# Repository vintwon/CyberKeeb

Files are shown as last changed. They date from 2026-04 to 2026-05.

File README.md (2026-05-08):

# CyberKeeb
render

## Some info...
This started as boredom, and evolved into my second keyboard! The theme came from some inspiration I saw from another keyboard on reddit, so I decided to do something similar. I wanted to use a rpi pico w but I didn't want to have extra space at the edge of the board, so I decided to make a daughterboard type situation. 
There are holes here: 



The traces are connected to the holes on the board which will then be connected to the rpi pico w which is mounted here using wires:



This way the usb-c port is centered in the back of the board and It gives me room to make the centerpiece of the keyboard:



Oh! And here is the pcb!





I went with a green and black theme simply because those are the colors of filament I have available right now. The geometrically interesting features are layerd, with each color on a different layer to provide depth. 
**ALSO QMK IS BEING USED YAYYY**

## BOM
!!! WARNING: ALIEXPRESS PRICES ARE VOLATILE AND SUBJECT TO CHAGE !!!

| Item | Link | Price(USD) | Notes |
|---|---|---|---|
| | | | |
| PCB | you must order the pcb yourself through your preferred pcb manufacturer. | ~$32 with shipping | Shipping and import taxes vary, for me it costs $32 on jlcpcb, which is the cheapest I could find. |
| KTT Kang White Switches | https://www.aliexpress.com/item/3256806762410255.html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 | $12.15 total | |
| DO-35 1N4148 diodes | https://www.aliexpress.com/item/3256811531564621.html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 | $2 | |
| Raspberry Pi Pico W | https://www.aliexpress.com/item/3256811531564621.html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 | $2 | |
| DUROCK stabilizers | https://www.aliexpress.com/item/3256806342416791.html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 | $3.85 | |
| Lubricant | https://www.aliexpress.com/item/3256803007713392.html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 | $9.67(for one) | Buy two |
| | | | |
| Total | | $71.34 | ALIEXPRESS PRICES ARE VOLATILE!!!! |

### <a href="https://cad.onshape.com/documents/5317cbb2be7b5bc0767f3a0c/">CAD in onshape :3</a>


## Zine!!!

zine-1

## Build instructions coming soon!

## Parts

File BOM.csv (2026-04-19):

Item | Link | Price(USD) | Notes
PCB | you must order the pcb yourself through your preferred pcb manufacturer. | ~$32 with shipping | Shipping and import taxes vary, for me it costs $32 on jlcpcb, which is the cheapest I could find.
Milky Yellow Pro Switches | https://www.aliexpress.com/item/3256803874880557.html?mp=1 | (2x needed) $13.82 total | make sure to order two!
DO-35 1N4148 diodes | https://www.aliexpress.com/item/3256811531564621.html?mp=1 | $1.85
Raspberry Pi Pico W | https://www.aliexpress.com/item/3256811531564621.html?mp=1 | $2
DUROCK stabilizers | https://www.aliexpress.com/item/3256806342416791.html?mp=1 | $3.85
Total |  | $53.52 | ALIEXPRESS PRICES ARE VOLATILE!!!!

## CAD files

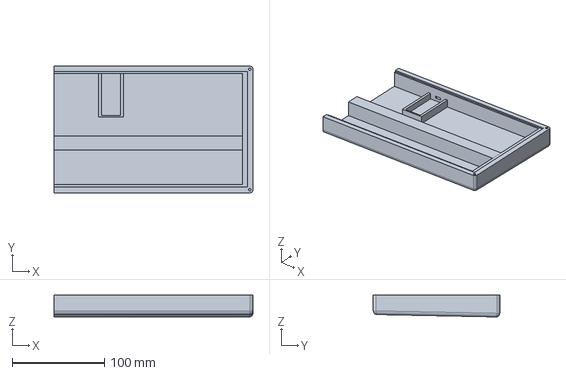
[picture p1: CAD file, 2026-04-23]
STEP files/Bottom Case/Case - Bottom Case.step
216.1 x 137.4 x 23.8 mm

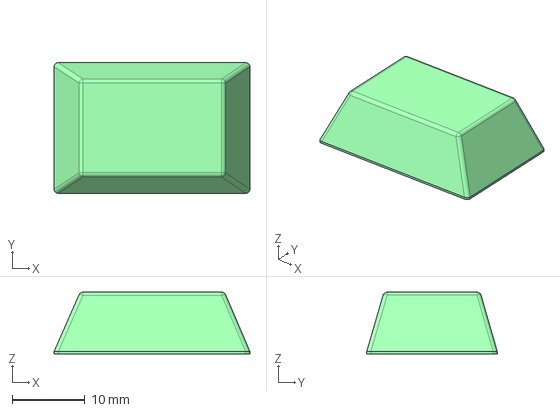
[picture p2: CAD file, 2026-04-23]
STEP files/keycaps/Keycaps - 1.5u.step
27.0 x 18.0 x 8.50 mm

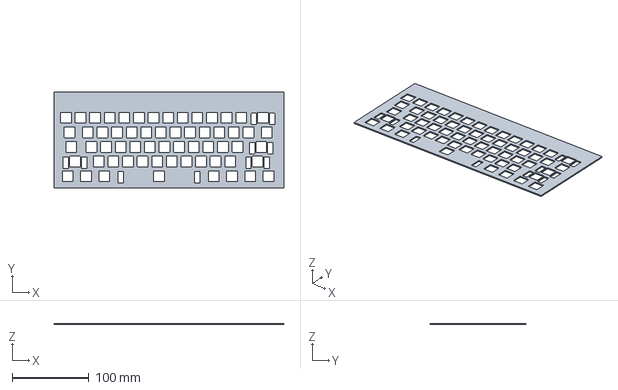
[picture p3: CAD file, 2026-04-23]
STEP files/Plate - Plate.step
300.0 x 125.0 x 1.50 mm

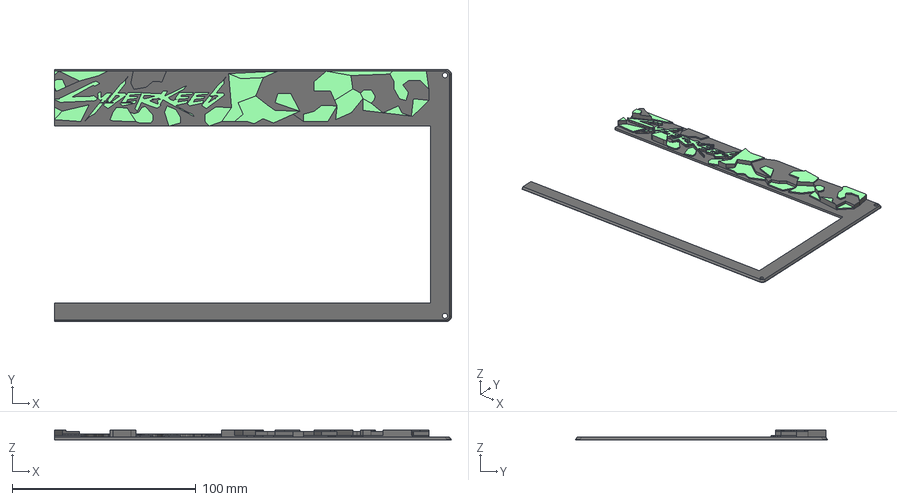
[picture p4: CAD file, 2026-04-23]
STEP files/Top Case/Case - Top Case.step
216.1 x 137.4 x 5.60 mm

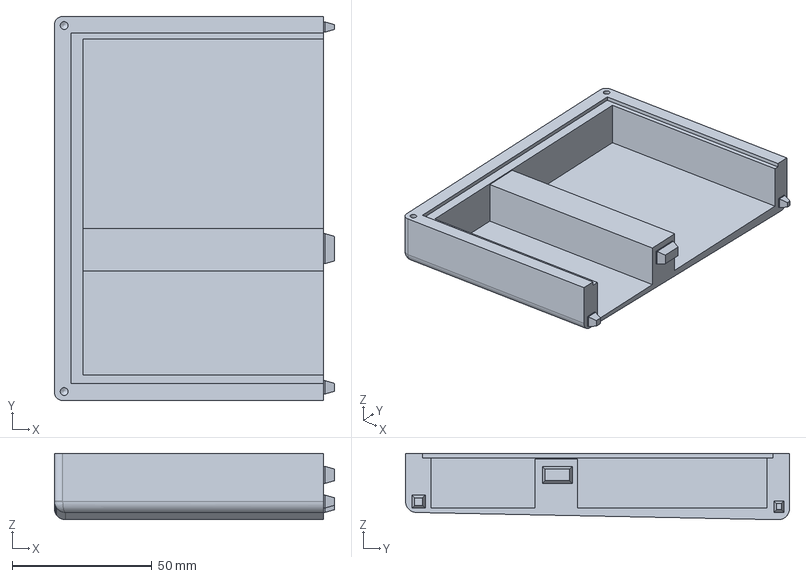
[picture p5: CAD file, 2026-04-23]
STEP files/Bottom Case/Case - Bottom Case2.step
100.3 x 137.4 x 23.8 mm

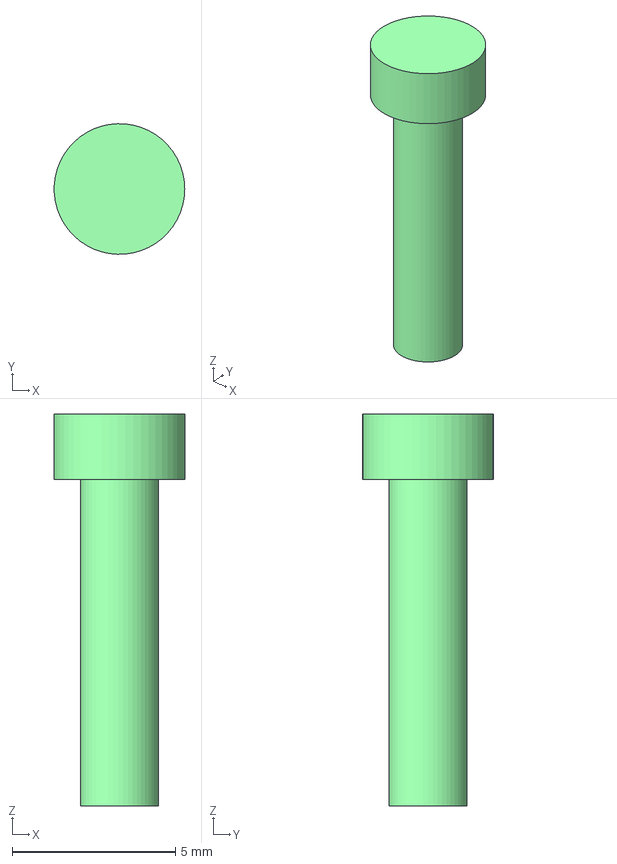
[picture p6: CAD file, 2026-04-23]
STEP files/Case - Pin.step
4.00 x 4.00 x 12.0 mm

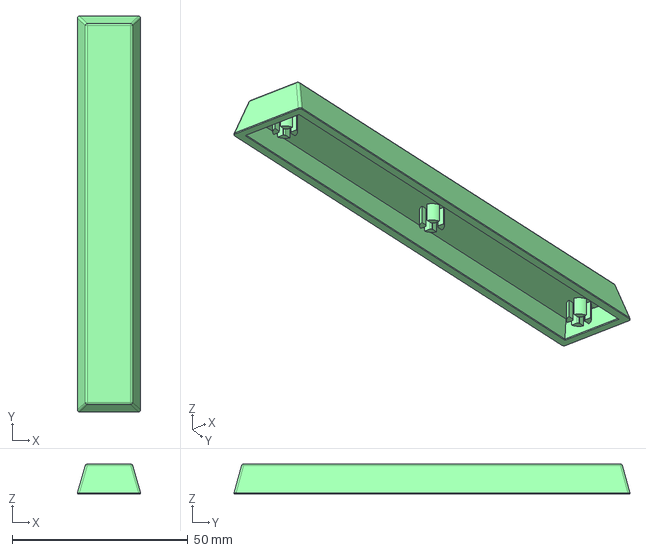
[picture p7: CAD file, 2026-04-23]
STEP files/keycaps/Keycaps - 6.25u.step
18.0 x 112.5 x 8.50 mm

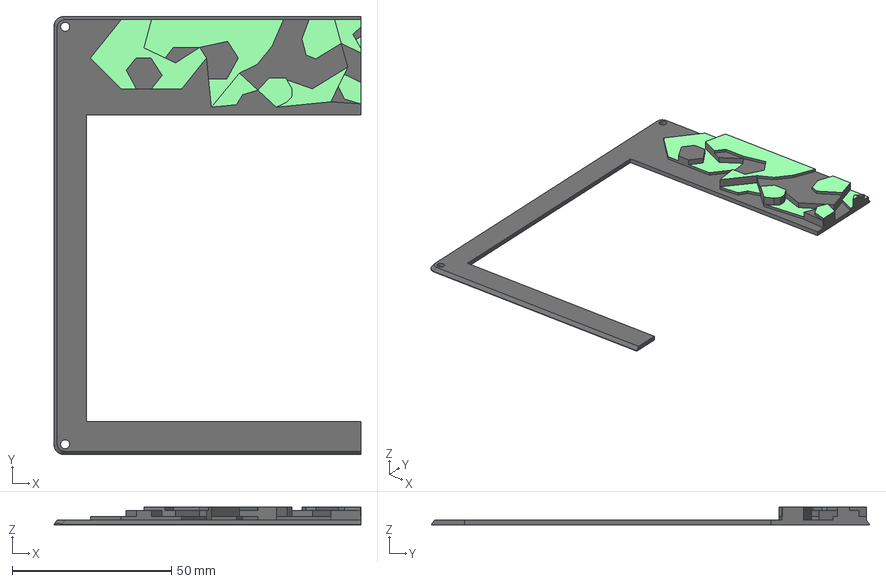
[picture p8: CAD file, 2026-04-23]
STEP files/Top Case/Case - Top Case2.step
96.3 x 137.4 x 5.60 mm

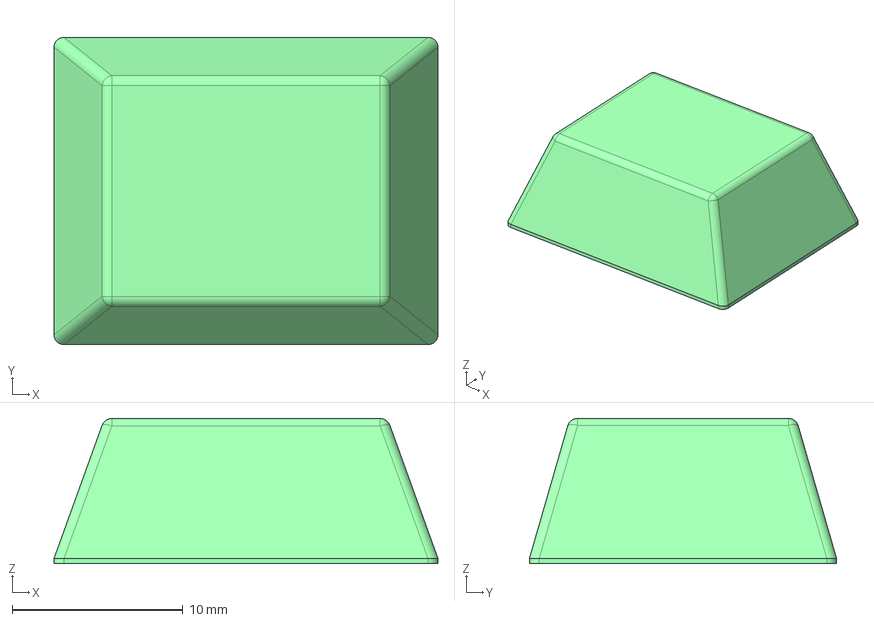
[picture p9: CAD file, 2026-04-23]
STEP files/keycaps/Keycaps - 1.25u.step
22.5 x 18.0 x 8.50 mm

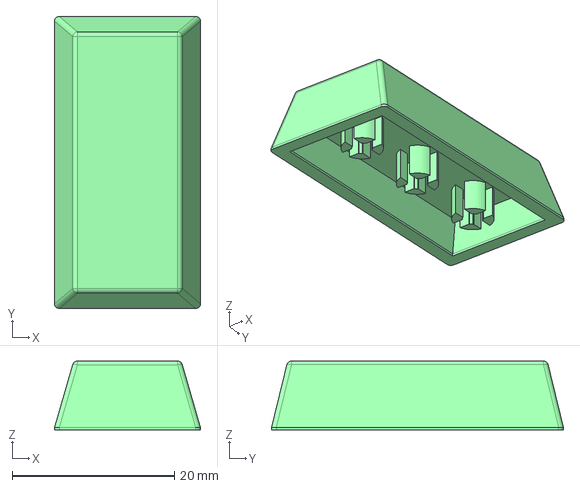
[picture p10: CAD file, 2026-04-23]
STEP files/keycaps/Keycaps - 2.0u.step
18.0 x 36.0 x 8.50 mm

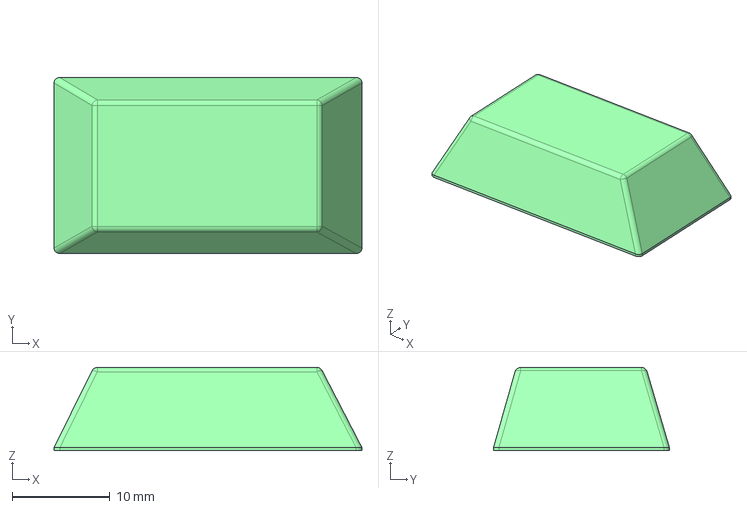
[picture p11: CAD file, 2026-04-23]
STEP files/keycaps/Keycaps - 1.75u.step
31.5 x 18.0 x 8.50 mm

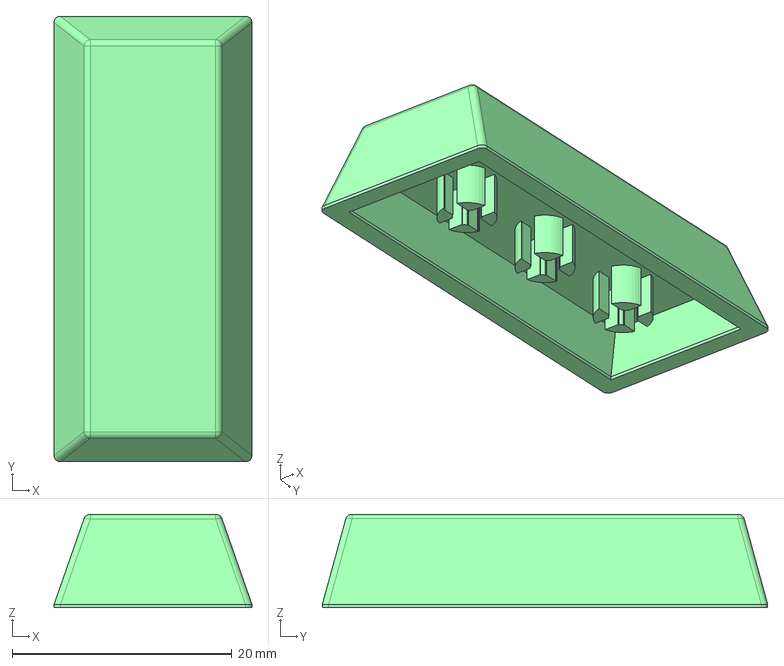
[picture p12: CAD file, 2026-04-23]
STEP files/keycaps/Keycaps - 2.25u.step
18.0 x 40.5 x 8.50 mm

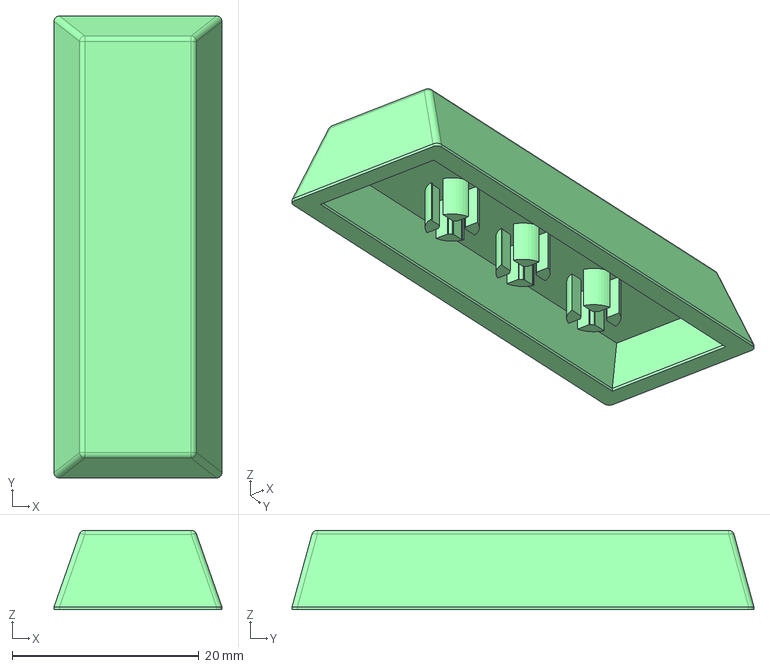
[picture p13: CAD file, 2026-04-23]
STEP files/keycaps/Keycaps - 2.75u.step
18.0 x 49.5 x 8.50 mm

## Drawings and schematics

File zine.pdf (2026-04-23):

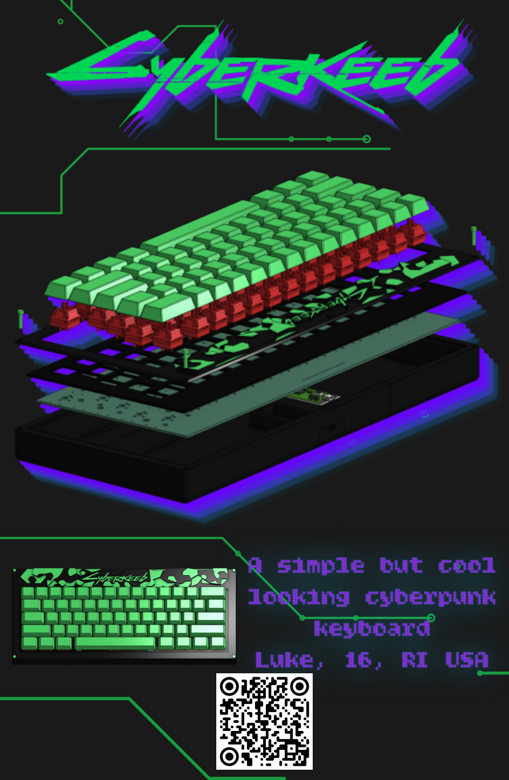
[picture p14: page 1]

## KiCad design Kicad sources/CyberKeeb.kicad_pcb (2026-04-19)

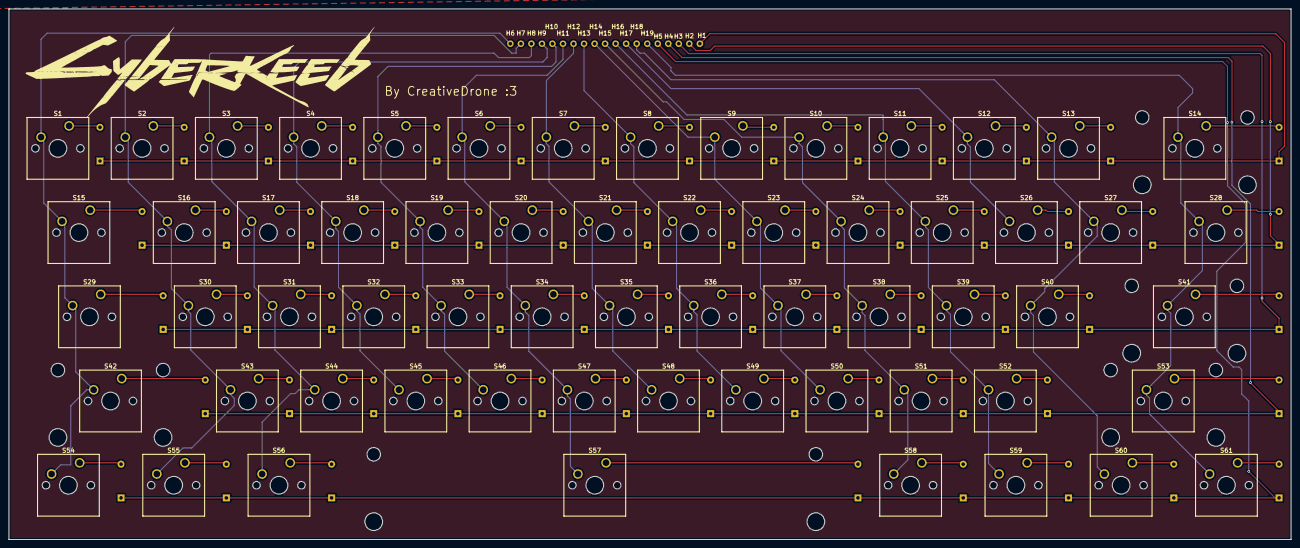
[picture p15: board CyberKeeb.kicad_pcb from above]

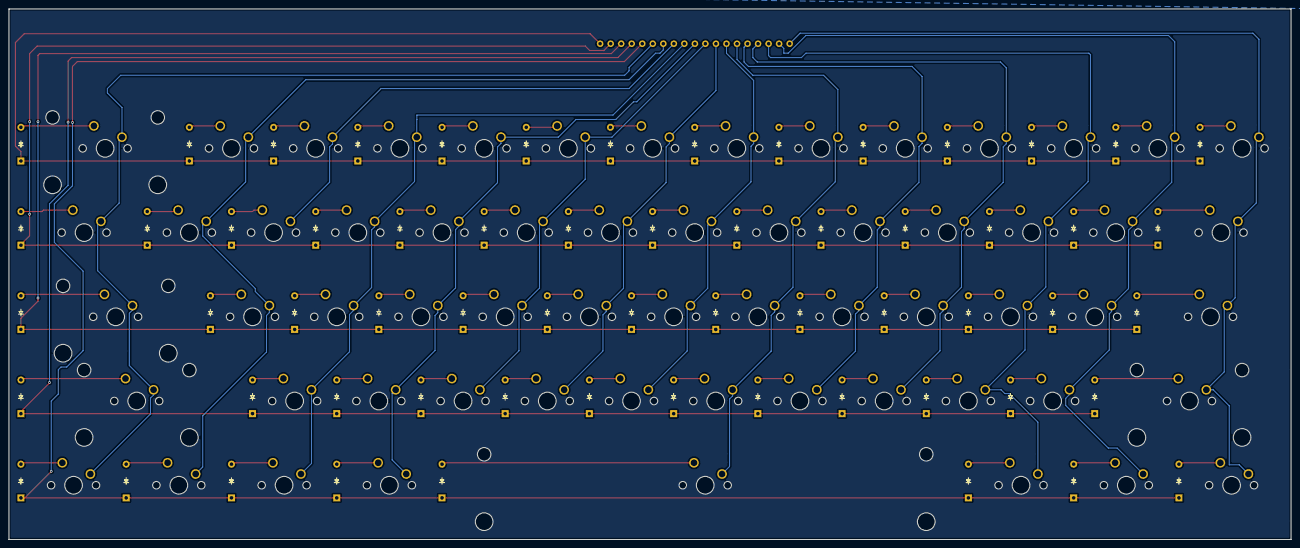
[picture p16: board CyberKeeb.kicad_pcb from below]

Board: 2 copper layers, 290.0 x 120.0 mm, 141 parts (61 on the bottom side), 80 nets.

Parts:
D1, D2, D3, D4, D5, D6, D7, D8, D9, D10, D11, D12, D13, D14, D15, D16, D17, D18, D19, D20, D21, D22, D23, D24, D25, D26, D27, D28, D29, D30, D31, D32, D33, D34, D35, D36, D37, D38, D39, D40, D41, D42, D43, D44, D45, D46, D47, D48, D49, D50, D51, D52, D53, D54, D55, D56, D57, D58, D59, D60, D61: Diode_DO-35
H1, H3, H4, H5, H6, H7, H8, H9, H10, H11, H12, H13, H14, H15, H16, H17, H18, H19: MountingHole_M3_3.2mm_Pad; CPH
H2: CPH
S1, S2, S3, S4, S5, S6, S7, S8, S9, S10, S11, S12, S13, S16, S17, S18, S19, S20, S21, S22, S23, S24, S25, S26, S27, S30, S31, S32, S33, S34, S35, S36, S37, S38, S39, S40, S43, S44, S45, S46, S47, S48, S49, S50, S51, S52: SW_Cherry_MX_1.00u_PCB
S14: SW_Cherry_MX_2.00u_PCB
S15, S28: SW_Cherry_MX_1.50u_PCB
S29: SW_Cherry_MX_1.75u_PCB
S41, S42: SW_Cherry_MX_2.25u_PCB
S53: SW_Cherry_MX_2.75u_PCB
S54, S55, S56, S58, S59, S60, S61: SW_Cherry_MX_1.25u_PCB
S57: SW_Cherry_MX_6.25u_PCB

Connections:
Column 0: H6.1, S1.2, S15.2, S29.2, S42.2, S54.2
Column 1: H7.1, S2.2, S16.2, S30.2, S43.2, S55.2
Column 2: H8.1, S3.2, S17.2, S31.2, S44.2, S56.2
Column 3: H9.1, S4.2, S18.2, S32.2, S45.2
Column 4: H10.1, S5.2, S19.2, S33.2, S46.2
Column 5: H11.1, S6.2, S20.2, S34.2, S47.2, S57.2
Column 6: H12.1, S7.2, S21.2, S35.2, S48.2
Column 7: H13.1, S8.2, S22.2, S36.2, S49.2
Column 8: H14.1, S9.2, S23.2, S37.2, S50.2
Column 9: H15.1, S10.2, S24.2, S38.2, S51.2, S58.2
Column 10: H16.1, S11.2, S25.2, S39.2, S52.2, S59.2
Column 11: H17.1, S12.2, S26.2
Column 12: H18.1, S13.2, S27.2, S40.2, S60.2
Column 13: H19.1, S14.2, S28.2, S41.2, S53.2, S61.2
unnamed: D1.2 (A), S1.1
unnamed: D2.2 (A), S2.1
unnamed: D3.2 (A), S3.1
unnamed: D4.2 (A), S4.1
unnamed: D5.2 (A), S5.1
unnamed: D6.2 (A), S6.1
unnamed: D7.2 (A), S7.1
unnamed: D8.2 (A), S8.1
unnamed: D9.2 (A), S9.1
unnamed: D10.2 (A), S10.1
unnamed: D11.2 (A), S11.1
unnamed: D12.2 (A), S12.1
unnamed: D13.2 (A), S13.1
unnamed: D14.2 (A), S14.1
unnamed: D15.2 (A), S15.1
unnamed: D16.2 (A), S16.1
unnamed: D17.2 (A), S17.1
unnamed: D18.2 (A), S18.1
unnamed: D19.2 (A), S19.1
unnamed: D20.2 (A), S20.1
unnamed: D21.2 (A), S21.1
unnamed: D22.2 (A), S22.1
unnamed: D23.2 (A), S23.1
unnamed: D24.2 (A), S24.1
unnamed: D25.2 (A), S25.1
unnamed: D26.2 (A), S26.1
unnamed: D27.2 (A), S27.1
unnamed: D28.2 (A), S28.1
unnamed: D29.2 (A), S29.1
unnamed: D30.2 (A), S30.1
unnamed: D31.2 (A), S31.1
unnamed: D32.2 (A), S32.1
unnamed: D33.2 (A), S33.1
unnamed: D34.2 (A), S34.1
unnamed: D35.2 (A), S35.1
unnamed: D36.2 (A), S36.1
unnamed: D37.2 (A), S37.1
unnamed: D38.2 (A), S38.1
unnamed: D39.2 (A), S39.1
unnamed: D40.2 (A), S40.1
unnamed: D41.2 (A), S41.1
unnamed: D42.2 (A), S42.1
unnamed: D43.2 (A), S43.1
unnamed: D44.2 (A), S44.1
unnamed: D45.2 (A), S45.1
unnamed: D46.2 (A), S46.1
unnamed: D47.2 (A), S47.1
unnamed: D48.2 (A), S48.1
unnamed: D49.2 (A), S49.1
unnamed: D50.2 (A), S50.1
unnamed: D51.2 (A), S51.1
unnamed: D52.2 (A), S52.1
unnamed: D53.2 (A), S53.1
unnamed: D54.2 (A), S54.1
unnamed: D55.2 (A), S55.1
unnamed: D56.2 (A), S56.1
unnamed: D57.2 (A), S57.1
unnamed: D58.2 (A), S58.1
unnamed: D59.2 (A), S59.1
unnamed: D60.2 (A), S60.1
unnamed: D61.2 (A), S61.1
Row 0: D1.1 (K), D2.1 (K), D3.1 (K), D4.1 (K), D5.1 (K), D6.1 (K), D7.1 (K), D8.1 (K), D9.1 (K), D10.1 (K), D11.1 (K), D12.1 (K), D13.1 (K), D14.1 (K), H1.1
Row 1: D15.1 (K), D16.1 (K), D17.1 (K), D18.1 (K), D19.1 (K), D20.1 (K), D21.1 (K), D22.1 (K), D23.1 (K), D24.1 (K), D25.1 (K), D26.1 (K), D27.1 (K), D28.1 (K), H2.1
Row 2: D29.1 (K), D30.1 (K), D31.1 (K), D32.1 (K), D33.1 (K), D34.1 (K), D35.1 (K), D36.1 (K), D37.1 (K), D38.1 (K), D39.1 (K), D40.1 (K), D41.1 (K), H3.1
Row 3: D42.1 (K), D43.1 (K), D44.1 (K), D45.1 (K), D46.1 (K), D47.1 (K), D48.1 (K), D49.1 (K), D50.1 (K), D51.1 (K), D52.1 (K), D53.1 (K), H4.1
Row 4: D54.1 (K), D55.1 (K), D56.1 (K), D57.1 (K), D58.1 (K), D59.1 (K), D60.1 (K), D61.1 (K), H5.1

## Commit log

2026-04-19 Expand README with project details and BOM
    Added detailed project information, BOM, and images.
2026-04-19 Fix README formatting and add PCB image
    Corrected formatting and added PCB image to README.
2026-04-19 Added kicad files
    [CyberKeeb.kicad_pcb, CyberKeeb.kicad_sch]
2026-04-19 added bom
    [BOM.csv]
2026-04-23 Added CAD and firmware files for the cyberkeeb keyboard project.
    [Case - Bottom Case.step, Case - Bottom Case2.step, Case - Pin.step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]
